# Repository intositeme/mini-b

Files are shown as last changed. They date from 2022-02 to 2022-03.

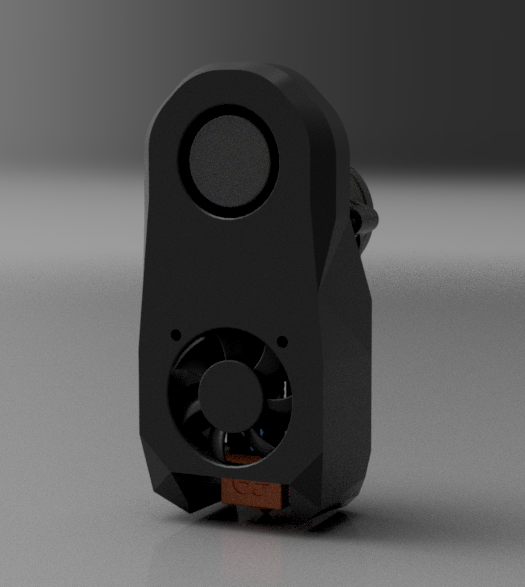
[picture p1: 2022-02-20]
images/render.png

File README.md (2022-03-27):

# mini-b
Toolhead for [Voron Design v0.1](https://vorondesign.com/voron0.1)

**Still in early dev. User at own risk.**

demo


**4010 Heater Fan** with **5015 parts blower fan**. Requires **different X-carriage** included. Accepts LGX lite with mounting plate (untested). Tested with [Kami extruder](https://github.com/intositeme/kami-mini).

Works with both Dragon & Mosquito hotends with **different** stls specific for each. Dragon's cowling is 2mm thicker thus will reduce Y by 2mm vs the Mosquito hotend.

**Note:** 4010 heater fan, the toolhead mounting screws passed 2 of the fan's holes, GDStime 4010 fans have a recessed hole which needs to be filled in to be flushed, if not the cowling plastic will break when tightened down. I used washers, printed part would do fine.

Initially thought toolhead will loose ~5mm in X/Y travel. Please check this on your printer, I some how managed to get more travel, ~ 3mm in X and 2mm in Y.

Known Issues, I might/might not fix
- ~~Fan ducts angle is pretty steep and hard to print properly (i just sand it down for cosmetic sake)~~
- ~~5015 front inlet cutout might not be centered to the fan, though it is in cad, could be due to GDStime fans being different?~~ Won't be fixing, been told some other fans sit nicely centered.
- ~~There might be a small gap in some corners of the print (new to CAD)~~

## Xcarriage

Added in X-carriage with different variations. Initial carriage was working with a different toolhead, but seems to be breaking with the added weight of this toolhead. 
- `X_Carriage - for v2.stl` - Standard to use with `lgx-mount.stl`

These following x-carriages requires the `lgx-mount-recessed.stl` and only the LGX-lite extruder
- `X_Carriage-extra beef.stl` - Extra thick +3mm 
- `X_Carriage-extra -extra beef.stl` - 5.5mm thick, requires 2 m3x4.2(diameter)x5 heat insert & 25mm BTS screw, screws go in from the front.
- `X_Carriage-extra -extra beef - mgn9.stl` - Used with mgn9 rails. Requires 2 m3x4.2(diameter)x5 heat insert & 30mm BTS screw, screws goes in from the back, ensure when tighten, the screws does not extend past the front and cause toolhead mounting issues.

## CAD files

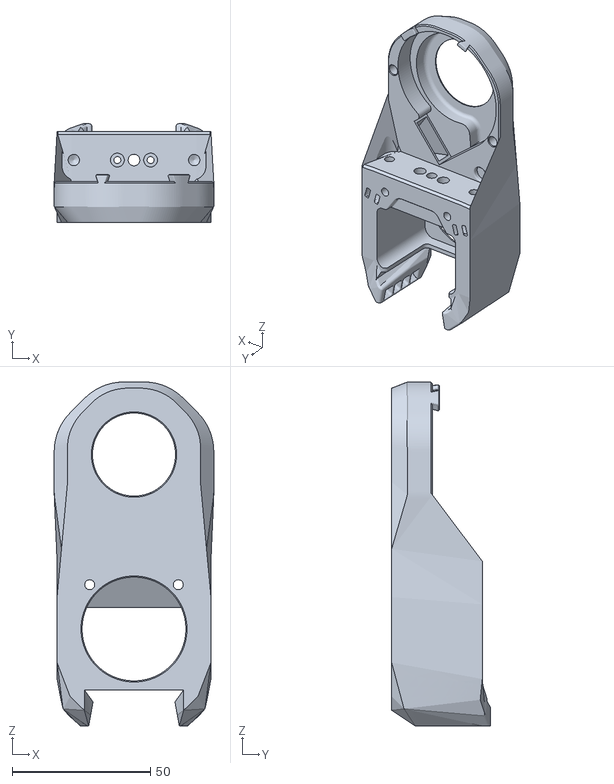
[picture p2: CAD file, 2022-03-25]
stls/Main Body with Ducts-Mosquito.stl
57.7 x 35.6 x 124.3

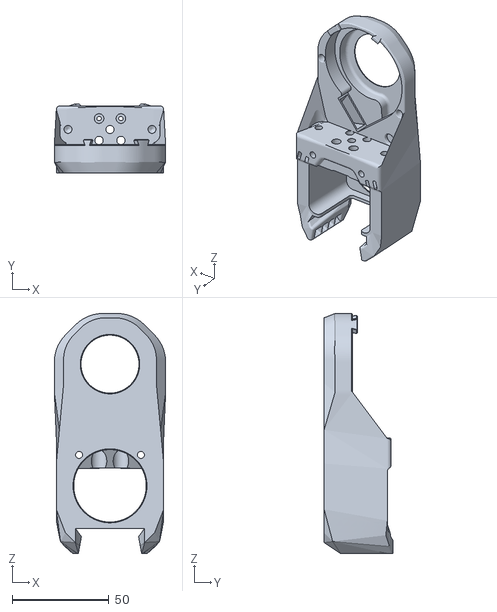
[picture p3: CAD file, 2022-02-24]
stls/Main Body with Ducts.stl
57.7 x 35.6 x 124.3

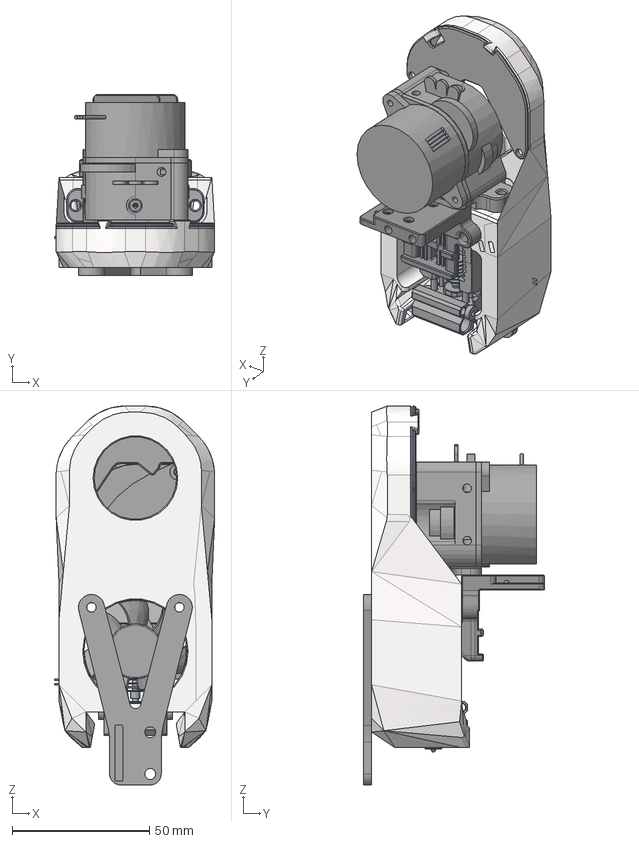
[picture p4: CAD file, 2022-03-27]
cad/Mini B - Mosquito - with Adxl mount.step
58.3 x 65.9 x 137.9 mm
40x40x10 DC Fan v1
ADXL Mount
LGX-Lite-Simplified-V6
mosquito_model_to_publish
Fan holder
X_Carriage -mgn9

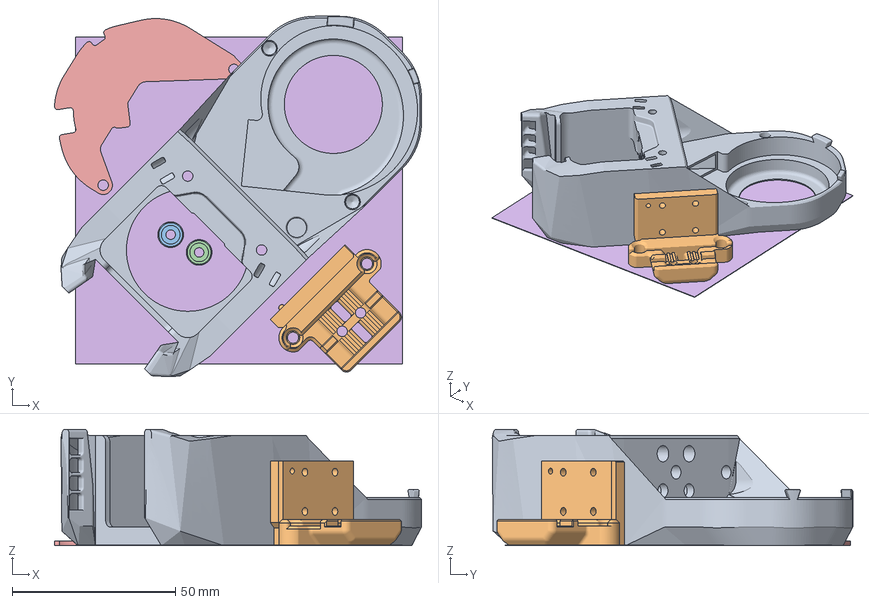
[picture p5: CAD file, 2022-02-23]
mini B.3mf
112.3 x 110.3 x 35.6 mm
Main Body with Ducts.stl
X_Carriage - for v2.stl
Hotend Holder_x2.stl x 2
Fan holder.stl
Shape-Box

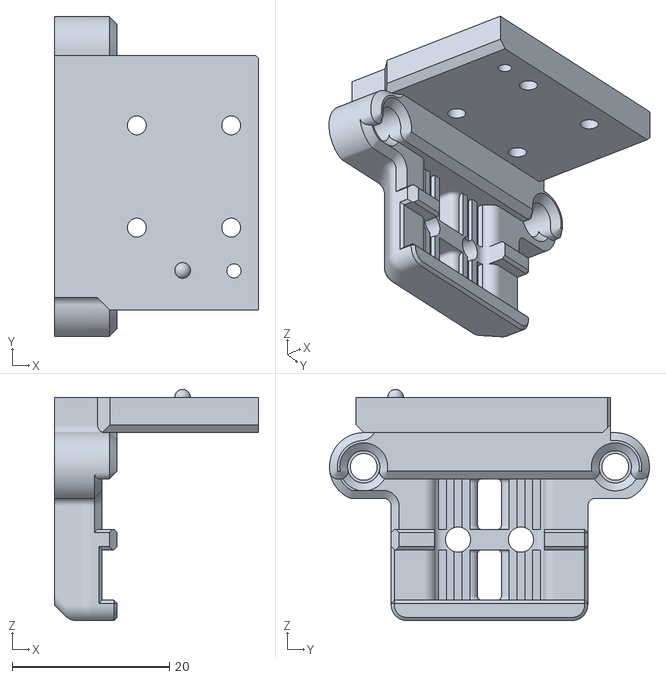
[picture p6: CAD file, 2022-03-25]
stls/X_Carriage - for v2.stl
26.0 x 40.7 x 29.4

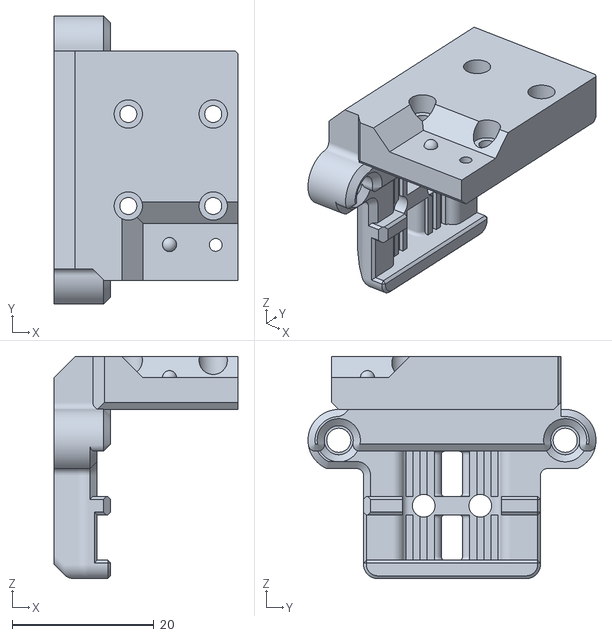
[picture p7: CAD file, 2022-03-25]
stls/X_Carriage-extra beef.stl
26.0 x 40.7 x 31.4

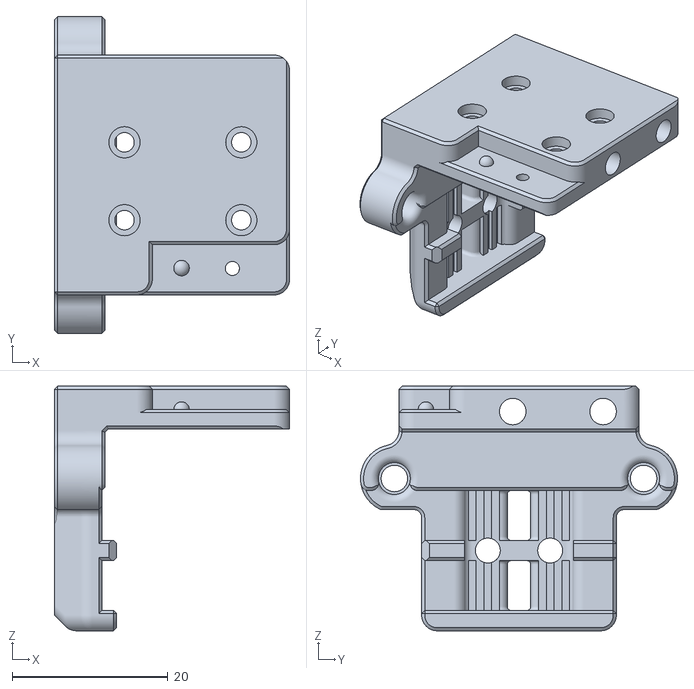
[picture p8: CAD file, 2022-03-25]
stls/X_Carriage-extra -extra beef - mgn9.stl
30.2 x 40.7 x 31.4

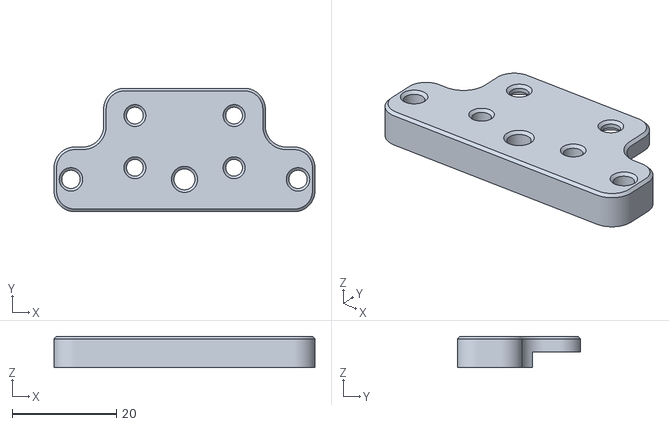
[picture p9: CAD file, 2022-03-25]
stls/lgx-mount-recessed.stl
50.0 x 23.7 x 6.00

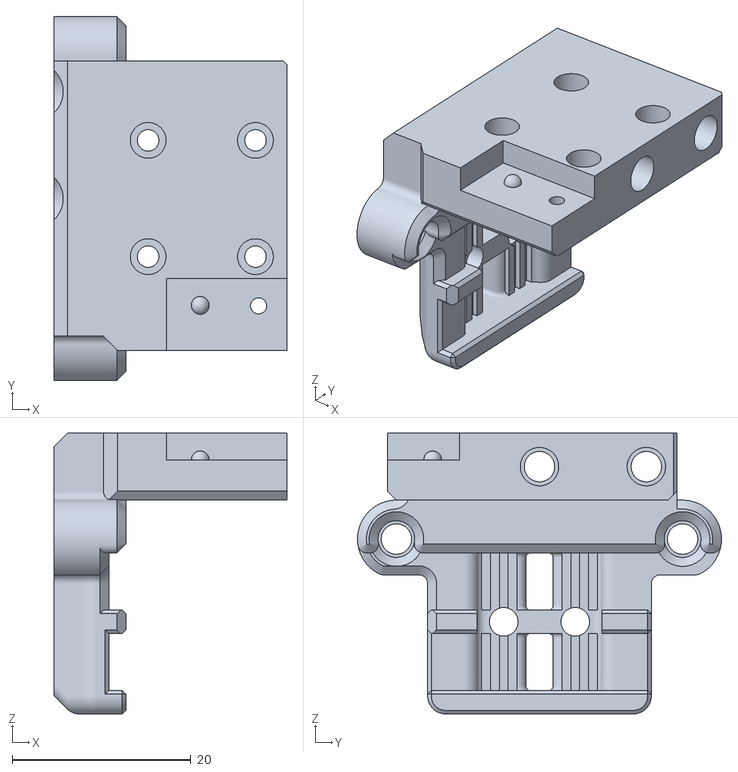
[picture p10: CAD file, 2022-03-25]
stls/X_Carriage-extra -extra beef.stl
26.0 x 40.7 x 31.4

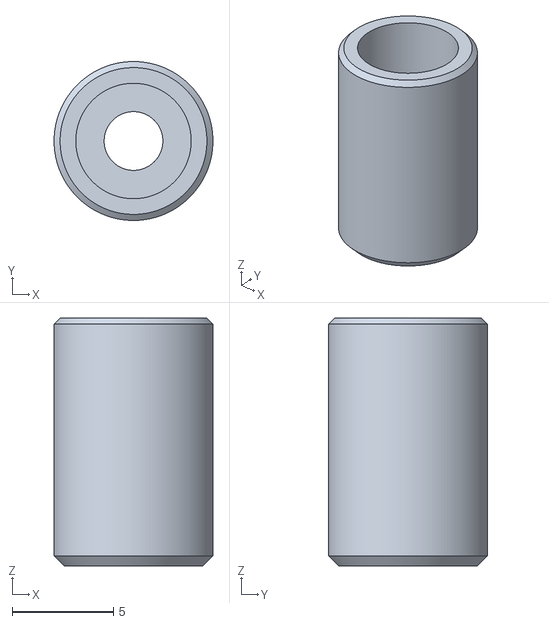
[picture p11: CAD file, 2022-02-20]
stls/Hotend Holder_x2.stl
7.85 x 7.85 x 12.3

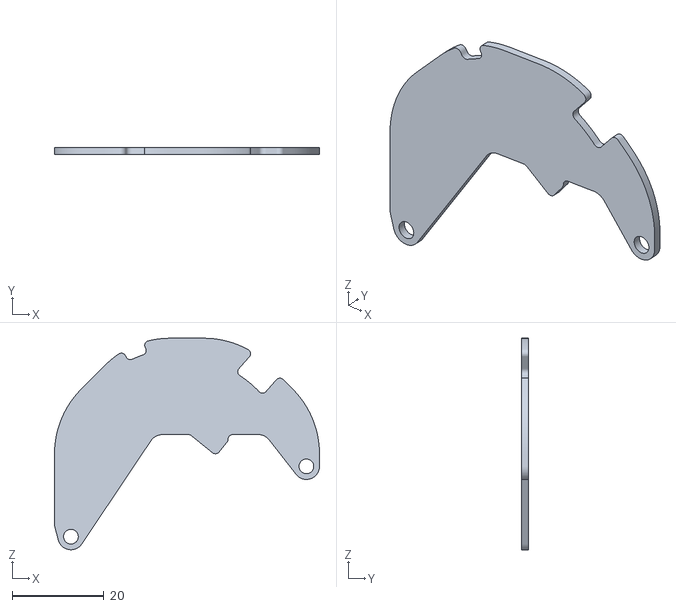
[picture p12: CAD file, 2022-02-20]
stls/Fan holder.stl
57.7 x 1.50 x 46.0

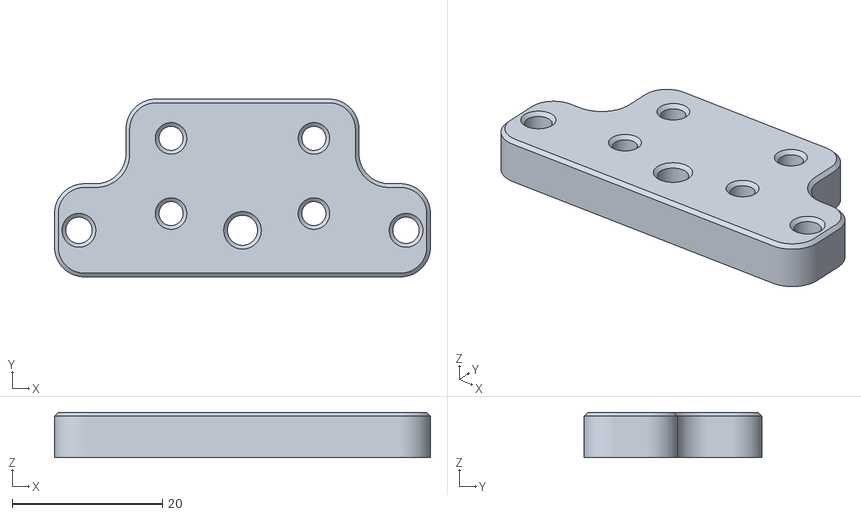
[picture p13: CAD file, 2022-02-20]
stls/lgx-mount.stl
50.0 x 23.7 x 6.00

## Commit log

2022-02-20 Reduced diameter of hotend holder part
    [Hotend Holder_x2.stl]
2022-02-21 Lowered Ziptie mounting points so that X carriage mounts will not interfer and potentially cause tool head to not mount flushed
    [Main Body with Ducts.stl]
2022-02-21 Change angles for better printability
    [Main Body with Ducts.stl, mini B.3mf]
2022-02-23 Increase back thickness, as dragon was interfering with back causing toolhead to be slanted when mounted.
    [Main Body with Ducts.stl, mini B.3mf]
2022-02-24 Gave part fan more space to cater for part shrinkage which might cause blades to rub on part.
    [Main Body with Ducts.stl]
2022-03-27 Added CAD files
    [Mini B - Mosquito - with Adxl mount.step]
